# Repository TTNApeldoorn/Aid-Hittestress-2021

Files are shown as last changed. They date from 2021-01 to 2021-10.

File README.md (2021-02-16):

# Aid-Hittestress-2021

## About this repository
This repository holds all information te build de AiD-Heatstress-sensor. 

**At this moment the repository presents work in progress. Changes may accur any time without notice!!**

# Disclaimer
The documentation of the TTN-Apeldoorn Aid-Hittestress-2021 sensor is distributed in the hope that it will be useful, but WITHOUT ANY WARRANTY; without even the 
implied warranty of MERCHANTABILITY or FITNESS FOR A PARTICULAR PURPOSE.

# License
The TTN-Apeldoorn Aid-Hittestress-2021 sensor is free soft- and hardware:
you can redistribute and/or modify it under the terms of a Creative Commons Attribution-NonCommercial 4.0 International License (http://creativecommons.org/licenses/by-nc/4.0/) by TTN-Apeldoorn (https://www.thethingsnetwork.org/community/apeldoorn/) E-mail: ttnapeldoorncoreteam@rfsee.nl

<br />This work is licensed under a <a rel="license" href="http://creativecommons.org/licenses/by-nc/4.0/">Creative Commons Attribution-NonCommercial 4.0 International License</a>.

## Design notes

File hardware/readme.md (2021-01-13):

# Hardware for Hittestress 2021 node.

## Documentation

## PCB design

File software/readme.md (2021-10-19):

# Software for Hittestress 2021 Node

The hittestress node is based on a Heltec SpaceCube board. This board offers besides a good LoRa stack, deep sleep facilities, LiPo power management, enough program memory and sufficient IO possibilities, see https://heltec.org/project/htcc-ab01/

### System Overview
Three sensors are connected to the node:

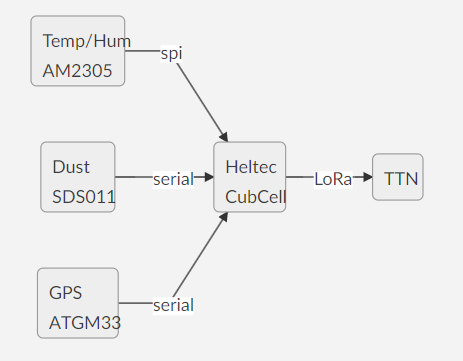
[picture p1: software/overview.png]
link


The Sensor sends each two minutes the Temperature, Humidity, Dust, PM10/PM2,5 to TTN. Each 4 hours the Status and GPS position of the sensor is send to TTN.

### Prototype
The development is currently in a prototyping phase. 
Below the prototype wiring diagram. 
link

### Power management
AT night the sensor is powered by 220V, during daylight the sensor is powered by the 3.7V LiPo. At night the LiPo will be charged.
To save power consumption, the CubeCell is forced into a deep sleep between two message cycles.  The GPS is powered via pin Vext, which is only active when requesting the GPS location.  The dust sensor SDS011 is forced in a sleep by a software command. The SDS011 air-fan needs 5V, so a DC step-up is placed in the supply line.

### Software prerequisites
- Arduino development environmnet minumum version 1.8
- Cube-Cell Development Framework V1.3 (can be installed in the Arduino board manager)
- DHT Adafruit sensor library
- TinyGPS++ library (Mikal Hart)

The LoRa stack and the SoftwareSerial is part of the CubeCell core. The adapted SDS011 library is present in the Hittestress source code.

### Arduino settings
Be sure that the correct board is selected and select the correct LoraWan parameters in the menu Arduino->tools:
- Board: CubeCel-Board (HTTC-AB01)
- LORAWAN settings: 
  - REGION_EU868
  - CLASS_A
  - OTAA
  - ADR ON
  - Upload UNCONFIRMED
  - Net Reservation OFF,
  - AT Support OFF,
  - RGB DEACTIVE   !!
  - Debug None

Note: RGB must be deactivated otherwise a conflict occurs with the GPS powersuppply Vext.
  
### TTN keys
The following OTAA keys must be set in the file LoRaWan.h viz. **appEui** and **appKey**.
**devEui** key must be left empty, this one is automatically set from the unique chipid of the HellTec board during startup.
This makes it possible the use of the same code for multiple sensors in your project.

### Payload binary 
Messages are sent on TTN port 15 (measurement data) and port 16 (status data)

Measurement payload on port 15:
- byte 0, 1:  Int16; Temperature * 100
- byte 2, 3: Int16; Humidity * 100
- byte 4, 5: Int16; PM10 * 100
- byte 6, 7: Int16; PM2.5 * 100
- byte 8, 9: Int16; Vbatttery * 1000

Status Payload on port 16:
- byte 0-3: Float: Latitude
- byte 4-7: Float: Longitude
- byte 8, 9: Int16; Altitude
- byte 10,11: InT16; Hdop * 1000
- byte 12,13: Int16; Vbatttery * 1000
- byte 14,15: Int16; Software version * 100

Note: Status message is sent each hour

### Output Payload decoder
The Payload decoder converts the binary payload to Json.<br>
Json example of a measurement message:
```
{ 
  "pm10": 0.9,
  "pm2p5": 0.46,
  "rh": 56.3,
  "temp": 7.5,
  "vbat": 4.17
}
```
Json Example of a status message
```
{ 
  "latitude": 52.2184104,
  "longitude": 5.964393,
  "alt": 56,
  "hdop": 1.8,
  "vbat": 4.026,
  "SwVer": 0.9
}
```

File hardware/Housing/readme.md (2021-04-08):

# Acrylic holder for SDS011
This holder is designed to hold the SDS011 sensor inside the sensor housing.

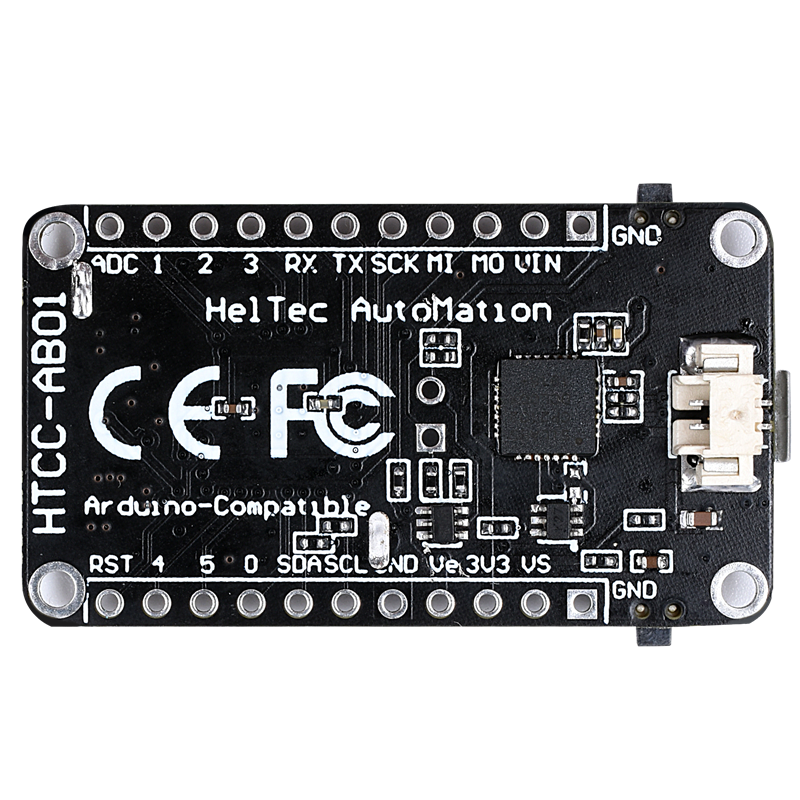
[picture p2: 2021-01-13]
hardware/documentation/board003.png

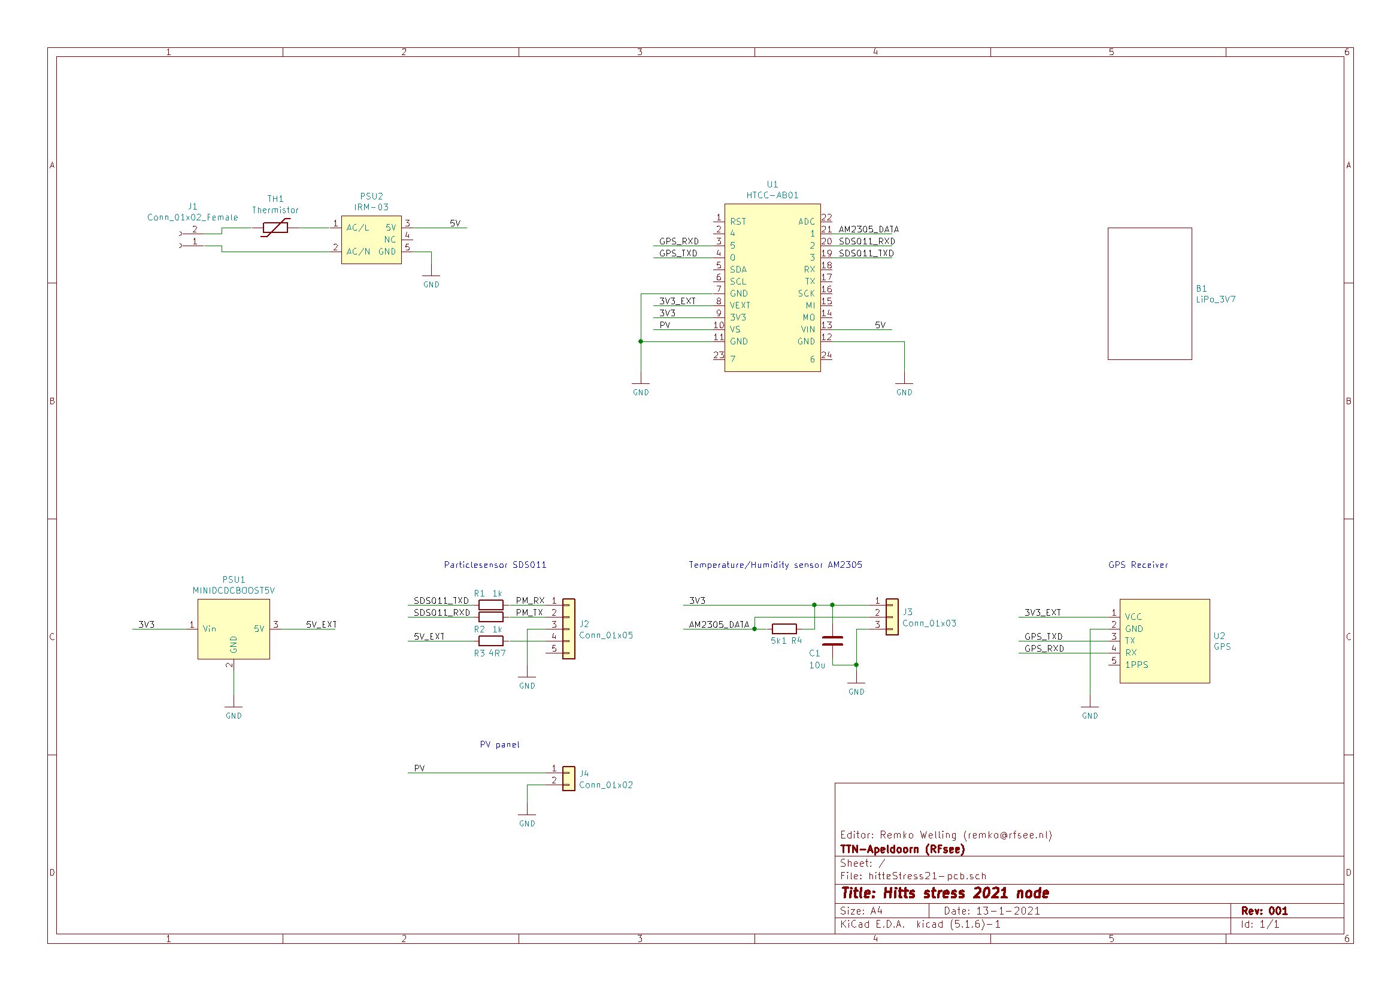
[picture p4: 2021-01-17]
hardware/pcb/hittstressV2_PCB_001.jpg

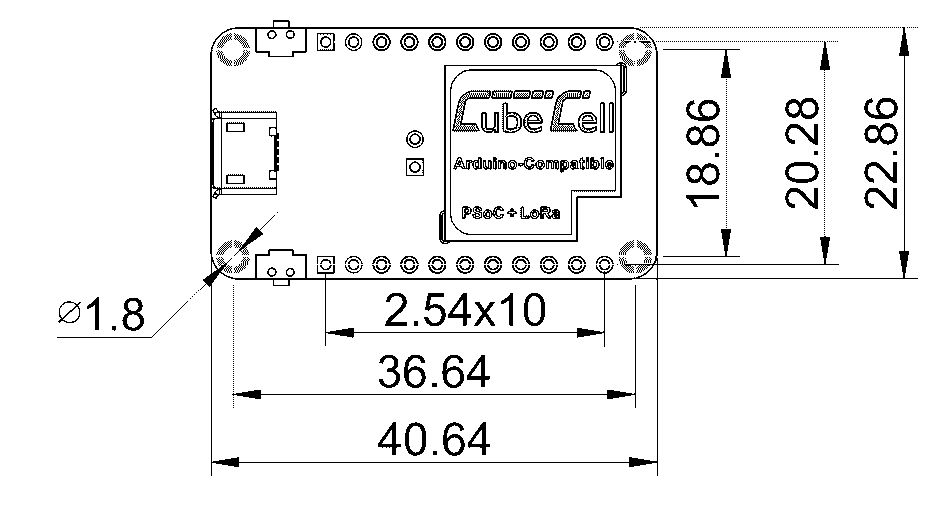
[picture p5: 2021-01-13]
hardware/documentation/BoardLayOut.jpg

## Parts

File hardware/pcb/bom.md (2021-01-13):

# BOM

## Mini DC-DC 5V Step-up Boost Converter 480mA
https://www.tinytronics.nl/shop/en/dc-dc-converters/step-up-(boost)/mini-dc-dc-5v-step-up-boost-converter-480ma

A small boost converter with output voltage of 5V.

Specifications:

    Input voltage range: 0.9 - 5V 
    Output voltage: 5V (fixed)
    Output current: 480 mA (max)
    Efficiency: ~85%
    Dimensions: 11 x 10.5 x 7.5 mm 

The  maximum output voltage is dependent on the input voltage:
|Input voltage(V)|Output current(mA)|
|--|--|
|0.9|7|
|1-1.5|40 - 100|
|1.5 -2 |100-150|
|2-3|150-380|
|>3|480|

The pinout (Vi, GND, Vo) is indicated on the module:

    Vi: Positive voltage input (paired with GND/min)
    GND: ground/min
    Vo: Positive voltage output (paired with GND/min)

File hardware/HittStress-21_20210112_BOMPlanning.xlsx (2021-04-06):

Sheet: RS (16+4)
 |  |  | Development |  | 2 |  | For development and prototyping (1)
 |  |  | Manufactured |  | 20 | + | Delivered
 |  |  | Devices |  | 22 |  | Total devices to be produced
Required | n | Value | Footprint | price/st/net | staffel | count | Price(Ex) | Price |  |  |  | Shop | Datasheet
TRUE | 1 | Lithium Ion Polymeer Accu - 3.7v 1200mAh |  | €9.58 | 1 | 22 | €210.76 | €255.02 | 22 |  |  | Kiwi Electronics | KW-2152
TRUE | 1 | Behuizing |  | €34.15 | 5 | 22 | €853.75 | €1033.04 | 25 |  |  | RS-Components | https://nl.rs-online.com/web/p/products/7560007/
TRUE | 1 | Voeding |  | €6.17 | 1 | 22 | €135.74 | €164.25 | 22 |  |  | RS-Components | https://nl.rs-online.com/web/p/products/1359226/
TRUE | 1 | AM2305 |  | €15.00 | 1 | 22 | €330.00 | €399.30 | 22 |  |  | Ali express ? | Stelpost
TRUE | 1 | Dubbelzijdige PCB 3x |  | €11.71 | 1 | 22 | €257.62 | €311.72 | 22 |  |  | Aisler
TRUE | 1 | SDS011 |  | €20.00 | 1 | 22 | €440.00 | €532.40 | 22 |  |  | Ali express ? | Stelpost
TRUE | 1 | SDS011 behuizingen |  | €2.00 | 1 | 22 | €44.00 | €53.24 | 22 |  |  | HOZA | Stelpost
TRUE | 3 | Wartels |  | €4.80 | 5 | 66 | €336.00 | €406.56 | 70 |  |  | HOZA | Stelpost
TRUE | 1 | LittleIfuse 0,05A |  | €3.68 | 1 | 22 | €80.96 | €97.96 | 22 |  |  | RS-Components | https://nl.rs-online.com/web/p/products/7756034/
TRUE | 1 | RS PRO 5mm Pitch, 2 Way PCB Terminal Block |  | €0.42 | 10 | 22 | €12.72 | €15.39 | 30 |  |  | RS-Components | https://nl.rs-online.com/web/p/pcb-terminal-blocks/8971159
TRUE | 1 | RS PRO, 2 Way, 1 Row, Straight PCB Terminal Block Header |  | €0.24 | 10 | 22 | €7.32 | €8.86 | 30 |  |  | RS-Components | https://nl.rs-online.com/web/p/pcb-headers/8971367
TRUE | 1 | 2.54mm Pitch 3 Way 1 Row Straight PCB Socket |  | €0.48 | 10 | 22 | €14.40 | €17.42 | 30 |  |  | RS-Components | https://nl.rs-online.com/web/p/pcb-sockets/2518187/
TRUE | 1 | 2.54mm Pitch 5 Way 1 Row Straight PCB Socket |  | €0.72 | 10 | 22 | €21.69 | €26.24 | 30 |  |  | RS-Components | https://nl.rs-online.com/web/p/pcb-sockets/2518200/
TRUE | 2 | SSW 2.54mm Pitch 11 Way 1 Row Straight PCB Socket |  | €1.15 | 1 | 44 | €41.82 | €50.60 | 44 |  |  | RS-Components | https://nl.rs-online.com/web/p/pcb-sockets/1981643/
 | 0 |  |  | €1.36 | 3 | 0 | €0.00 | €0.00 | 0 |  |  | RS-Components
 | 0 |  |  | €6.67 | 1 | 0 | €0.00 | €0.00 | 0 |  |  | RS-Components
 | 0 |  |  | €2.03 | 5 | 0 | €0.00 | €0.00 | 0 |  |  | RS-Components
TRUE | 1 | SDS connector PCB |  | €2.03 | 5 | 22 | €50.75 | €61.41 | 25 |  |  | RS-Components | https://nl.rs-online.com/web/p/products/8201598/
TRUE | 1 | ATGM336H GPS |  | €5.00 | 1 | 22 | €110.00 | €133.10 | 22 |  |  | Ali express ?
TRUE | 2 | 1K |  | €0.12 | 10 | 44 | €6.00 | €7.26 | 50 |  |  | RS-Components | https://nl.rs-online.com/web/p/products/7078221/
TRUE | 1 | HTCC-AB01 |  | €11.99 | 1 | 22 | €263.78 | €319.17 | 22 |  |  | Helltec | Stelpost
TRUE | 1 | 4R7 |  | €0.10 | 25 | 22 | €2.50 | €3.02 | 25 |  |  | RS-Components | https://nl.rs-online.com/web/p/through-hole-fixed-resistors/6833806/
TRUE | 1 | 5K1 |  | €0.10 | 25 | 22 | €2.50 | €3.02 | 25 |  |  | RS-Components | https://nl.rs-online.com/web/p/through-hole-fixed-resistors/0148253/
 | 0 |  |  | €2.03 | 5 | 0 | €0.00 | €0.00 | 0 |  |  | RS-Components
 | 0 |  |  | €2.03 | 5 | 0 | €0.00 | €0.00 | 0 |  |  | RS-Components
 | 0 |  |  | €2.03 | 5 | 0 | €0.00 | €0.00 | 0 |  |  | RS-Components | Stelpost
TRUE | 1 | Wurth Elektronik, 2109 2.54mm Pitch, 3 Way PCB Terminal Block |  | €1.20 | 5 | 22 | €29.95 | €36.24 | 25 |  |  | RS-Components | https://nl.rs-online.com/web/p/pcb-terminal-blocks/1919097/
TRUE | 1 | Mini DC-DC 5V Step-up Boost Converter 480mA |  | €1.65 | 1 | 22 | €36.30 | €43.92 | 22 |  |  | Tinytronics | https://www.tinytronics.nl/shop/en/dc-dc-converters/step-up-(boost)/mini-dc-dc-5v-step-up-boost-converter-480ma
 |  |  |  |  |  |  | Ex | VAT |  |  | +
 |  |  | Subtotaal |  |  |  | €3288.56 | €3979.16 |  | €0.00
 |  |  | Onvoorzien | 10% |  |  | €328.86
 |  |  |  |  |  |  |  |  |  |  | +
 |  |  |  |  |  |  | €3617.41 | €4377.07 |  | €4377.07 |  | Project price excl.VAT for 20 devices
 |  |  |  |  |  |  | €180.87 | €218.85 |  |  |  | Commercial Price/Pice excl.VAT
 |  |  |  |  |  |  |  | €198.96 |  |  |  | Community Price/Pice incl.VAT

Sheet: BOM
Ref | n | Value | Footprint | Shop | Datasheet
C1 | 1 | 10n | SMD:1206_3216 | RS-Components | https://nl.rs-online.com/web/p/mlccs-multilayer-ceramic-capacitors/2989220/
D1 | 1 | BAT54S | SMD:SOT-23 | RS-Components | https://nl.rs-online.com/web/p/rectifier-diodes-schottky-diodes/5444584/
J1 | 1 | RJ11-6 | RJ12_Amphenol_54601 | RS-Components | https://nl.rs-online.com/web/p/ethernet-connectors/1370999/
Q1 | 1 | BC547 (BC847) | SMD:SOT-323_SC-70 (SOT23) | RS-Components | https://nl.rs-online.com/web/p/bjt-bipolar-transistors/6900091/
R1, | 1 | 10K | SMD:R_1206_3216 | RS-Components | https://nl.rs-online.com/web/p/surface-mount-fixed-resistors/7219908/
R2, R3, R4, R8 | 1 | 1K | SMD:R_1206_3216 | RS-Components | https://nl.rs-online.com/web/p/surface-mount-fixed-resistors/9013724/
R5, R6, R7 | 3 | 180 | SMD:R_1206_3216 | RS-Components | https://nl.rs-online.com/web/p/surface-mount-fixed-resistors/7219762/
Housing | 1 |  | Hammond 1591 ABS Enclosure, Flanged | RS-Components | https://nl.rs-online.com/web/p/general-purpose-enclosures/8180514/
PCB | 1 |  | Aisler, PCB & Stencil | Aisler | http://www.aisler.net
header | 2 | FemalePCBHeader | 1 Row Straight PCB Socket | RS-Components | https://nl.rs-online.com/web/p/pcb-sockets/0252399/
U1 | 1 | TTGO_LoRa32_V11 | TTGO LoRa32 | Tinytronics | https://www.tinytronics.nl/shop/nl/platforms/ttgo/lilygo-ttgo-lora32-868mhz-esp32
Cable | 1 | RJ11 | InLine Modularkabel RJ12, Male/Male, 6adrig, 6P6C, 1m | Netwerkwinkel.com | https://www.netwerkwinkel.com/Verleng--en-aansluitkabels/Telefoonkabels/RJ10---RJ11---RJ12-kabels/InLine/InLine-Modularkabel-RJ12-Male-Male-6adrig-6P6C-2m-188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
PSU | 1 | 5V-miniUSB-Adapter | 5W Plug In Power Supply 5V dc, 1A | RS-Components | https://nl.rs-online.com/web/p/ac-dc-adapters/1217116/
miniUSB | 1 | Type B Mini USB Connector | Through Hole Mount Receptacle | RS-Components | https://nl.rs-online.com/web/p/usb-connectors/6741350/
J | 1 |  |  | RS-Components | https://docs.rs-online.com/898e/0900766b8157d634.pdf

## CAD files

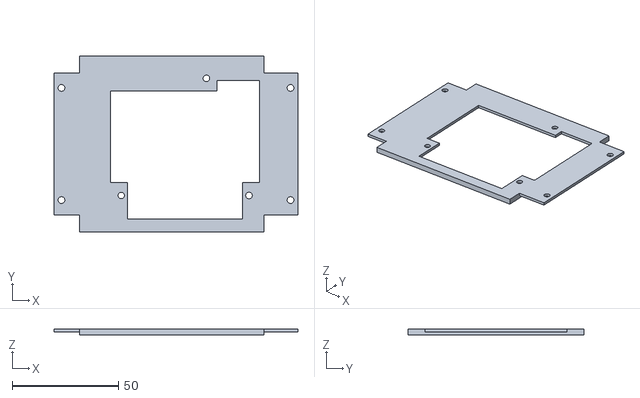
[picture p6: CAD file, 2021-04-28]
hardware/Housing/SDS011Mount-3D_004.stl
114.6 x 82.6 x 2.90

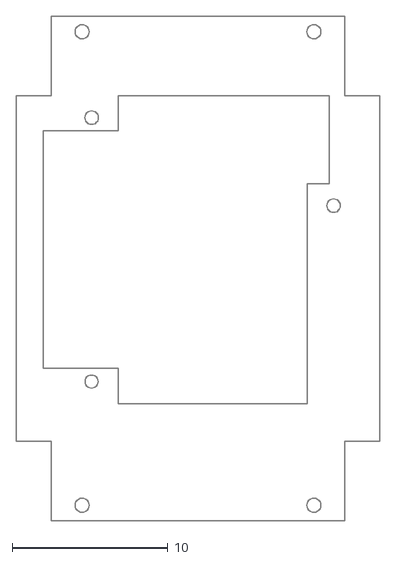
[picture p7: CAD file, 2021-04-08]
hardware/Housing/SDS011Mount_004.dxf
23.3 x 32.3

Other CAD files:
hardware/documentation/CubeCell_CAD2014.dwg
hardware/Housing/HousingDrillMeasures_001.skp
hardware/Housing/SDS011Mount-3D_004.skp
hardware/Housing/SDS011Mount_001.skp
hardware/Housing/SDS011Mount_002.skp
hardware/Housing/SDS011Mount_003.skp
hardware/Housing/SDS011Mount_004.skp

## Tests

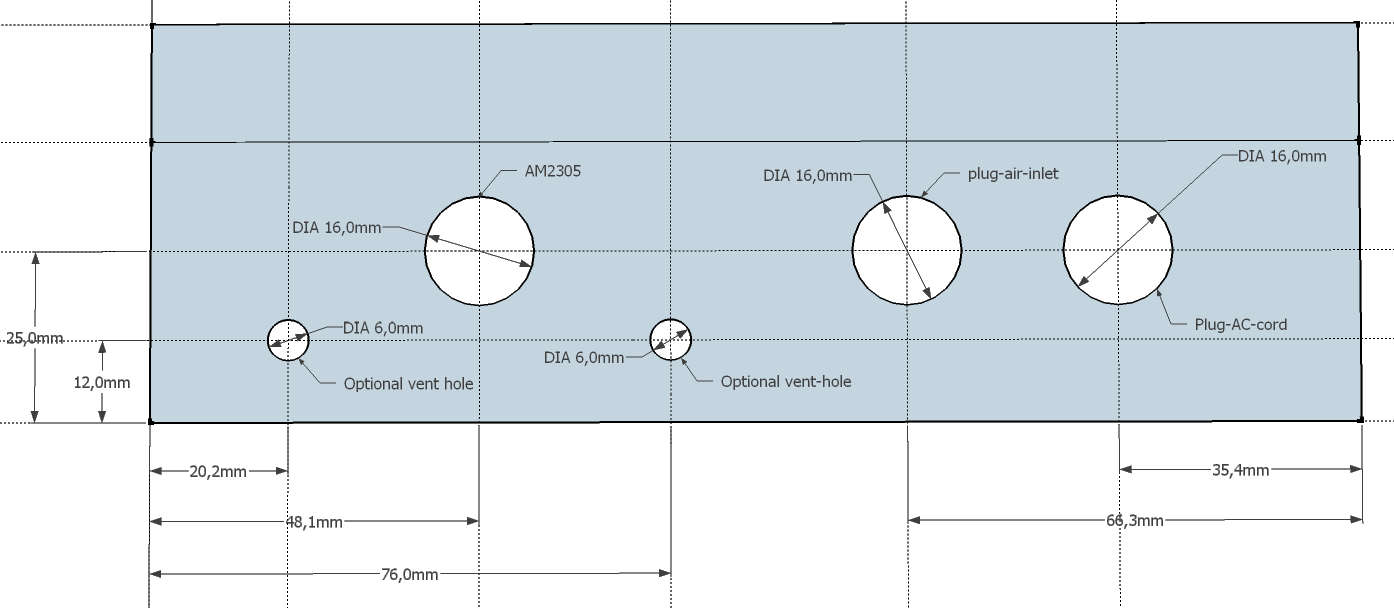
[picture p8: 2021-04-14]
hardware/Housing/HousingDrillMeasures_001_transparent.png

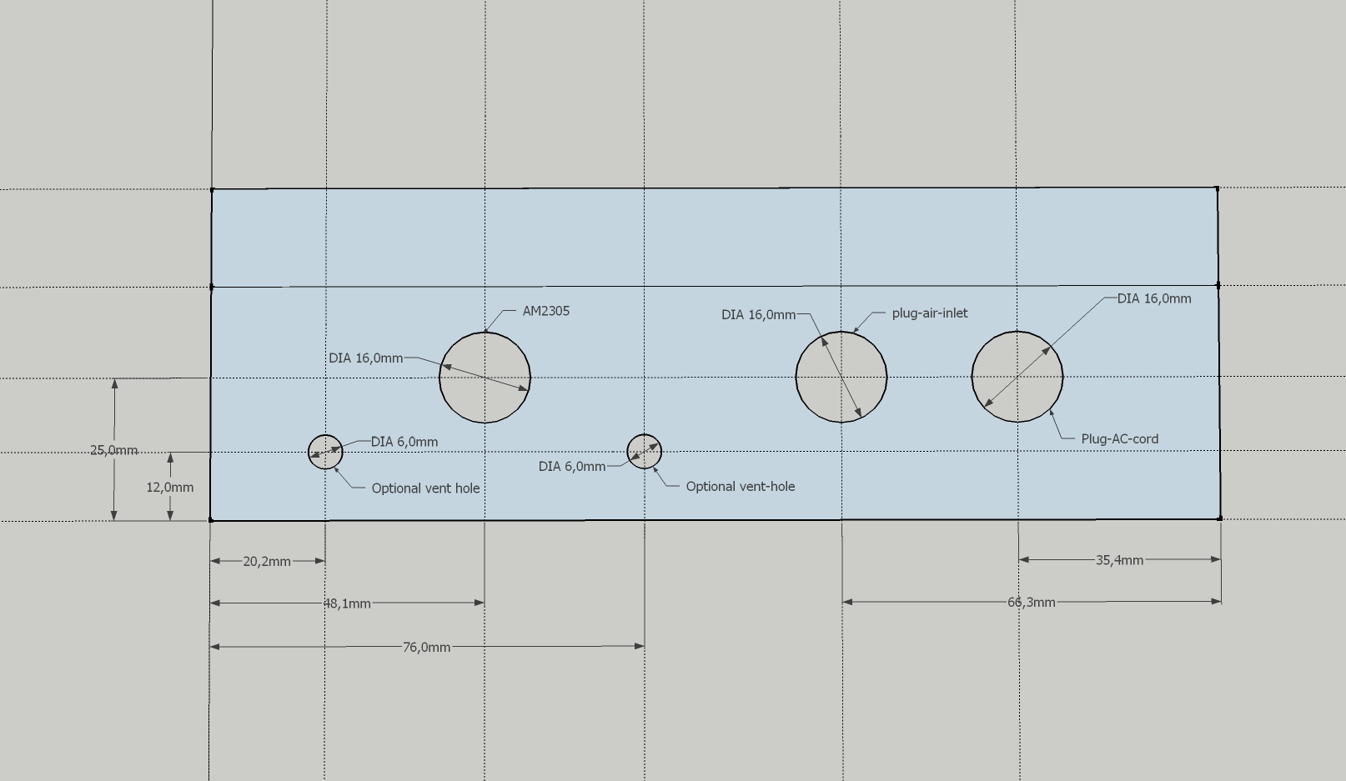
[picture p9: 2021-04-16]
hardware/Housing/HousingDrillMeasures_001.png

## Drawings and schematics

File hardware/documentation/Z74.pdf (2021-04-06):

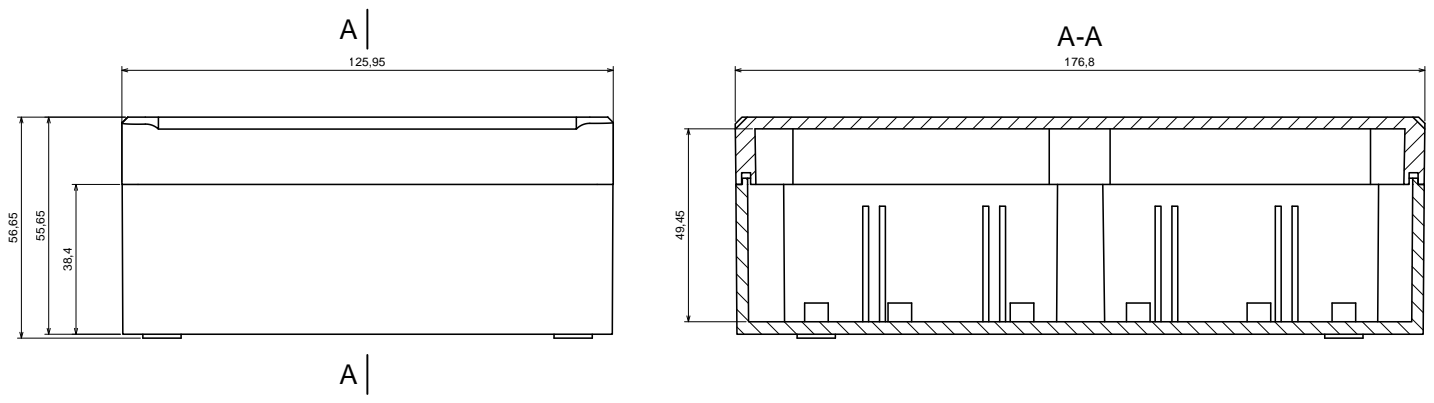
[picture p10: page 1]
Product model Format: A3 Scale 1:1; Tolerance: +/- 0.5 Material: PS, ABS Enclosure Z74 - assembly All rights reserved, Copyright Kradex 2016

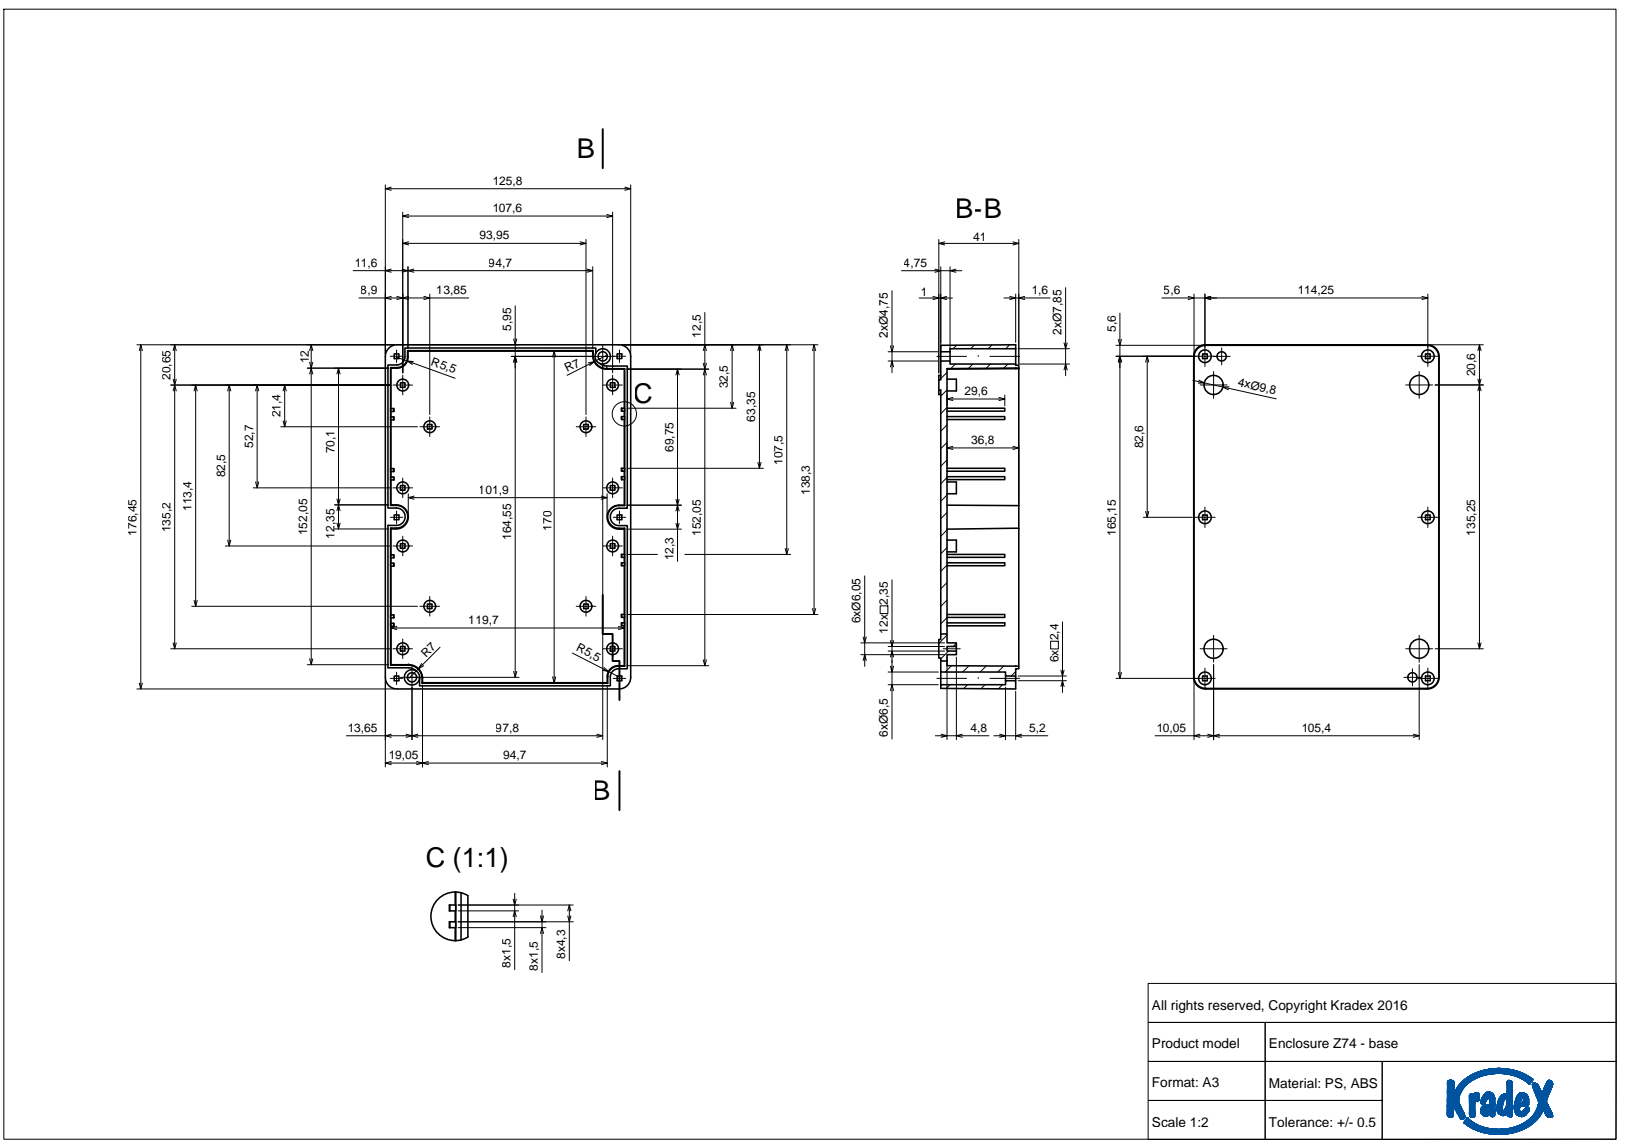
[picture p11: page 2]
Product model Format: A3 Scale 1:2; Tolerance: +/- 0.5 Material: PS, ABS Enclosure Z74 - base All rights reserved, Copyright Kradex 2016 125,8

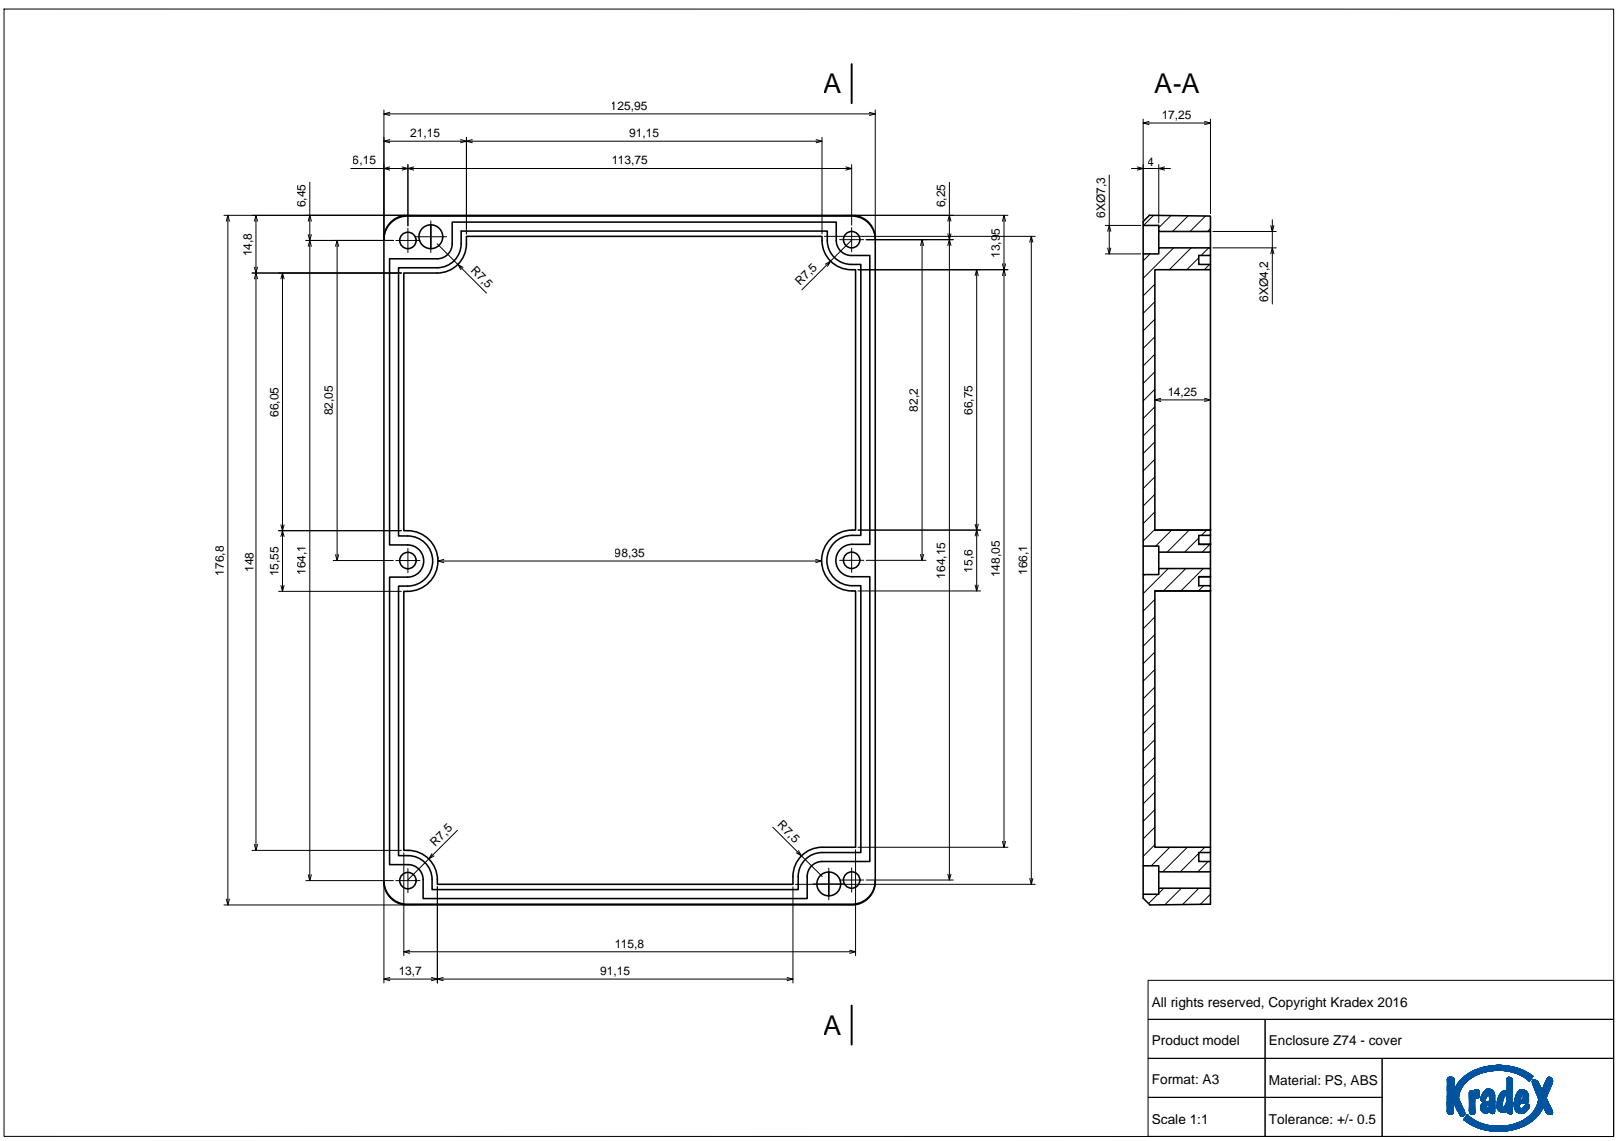
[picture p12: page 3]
Product model Format: A3 Scale 1:1; Tolerance: +/- 0.5 Material: PS, ABS Enclosure Z74 - cover All rights reserved, Copyright Kradex 2016 AA

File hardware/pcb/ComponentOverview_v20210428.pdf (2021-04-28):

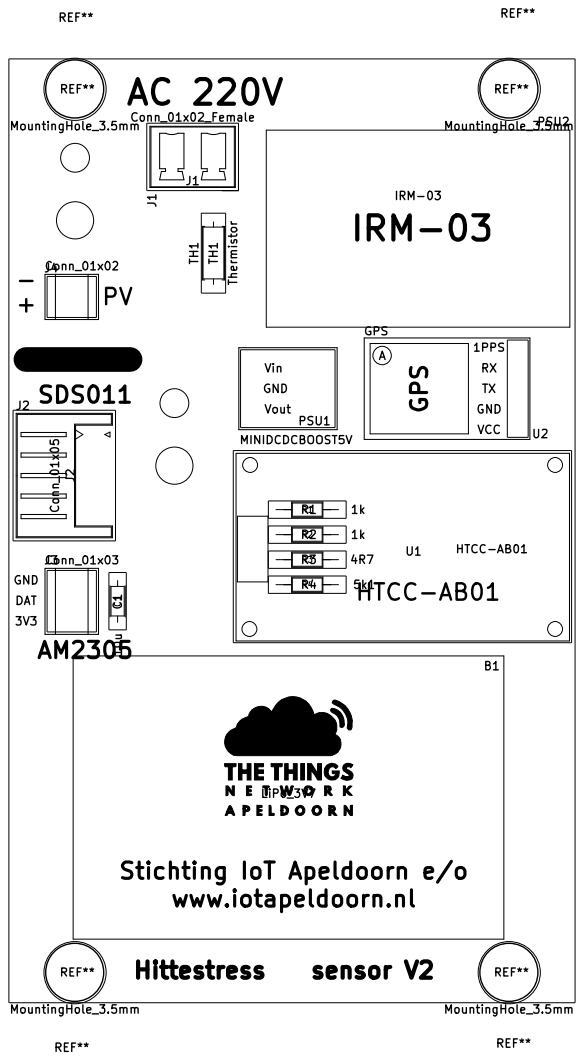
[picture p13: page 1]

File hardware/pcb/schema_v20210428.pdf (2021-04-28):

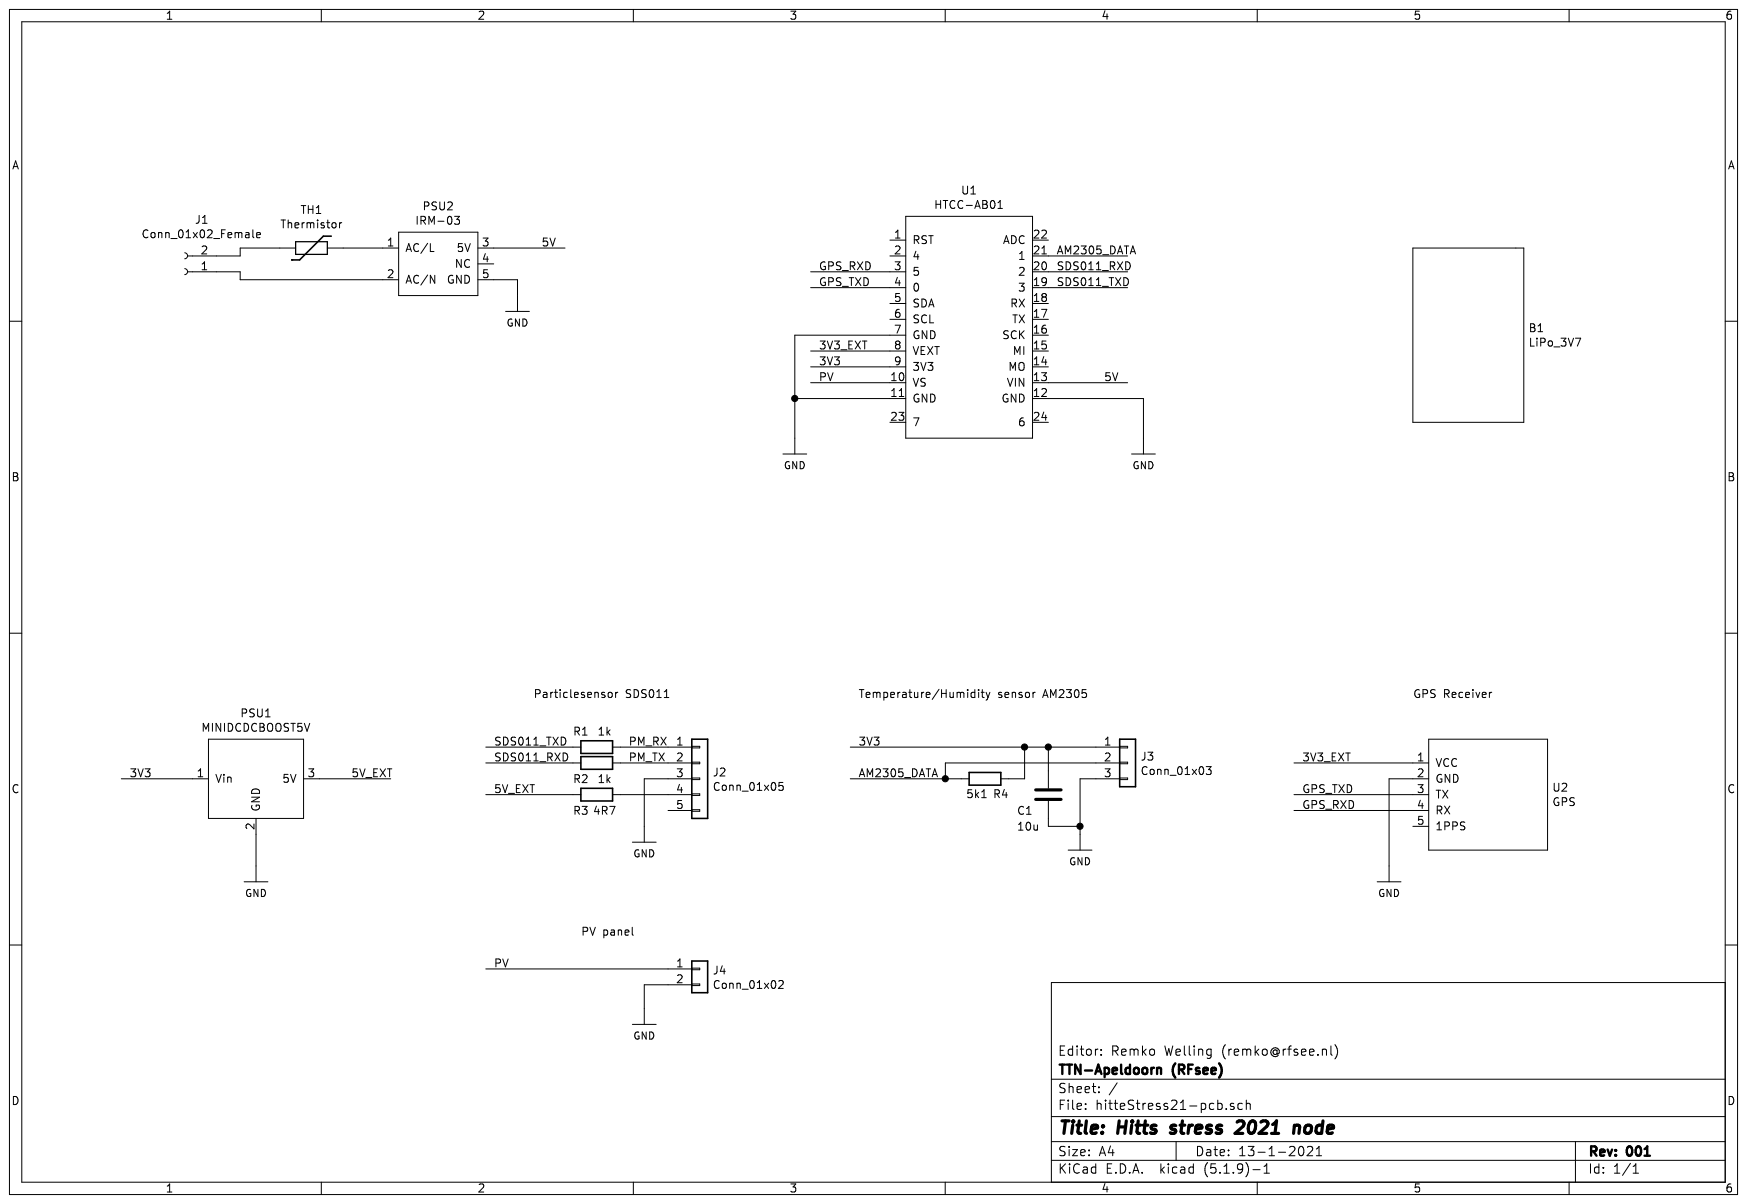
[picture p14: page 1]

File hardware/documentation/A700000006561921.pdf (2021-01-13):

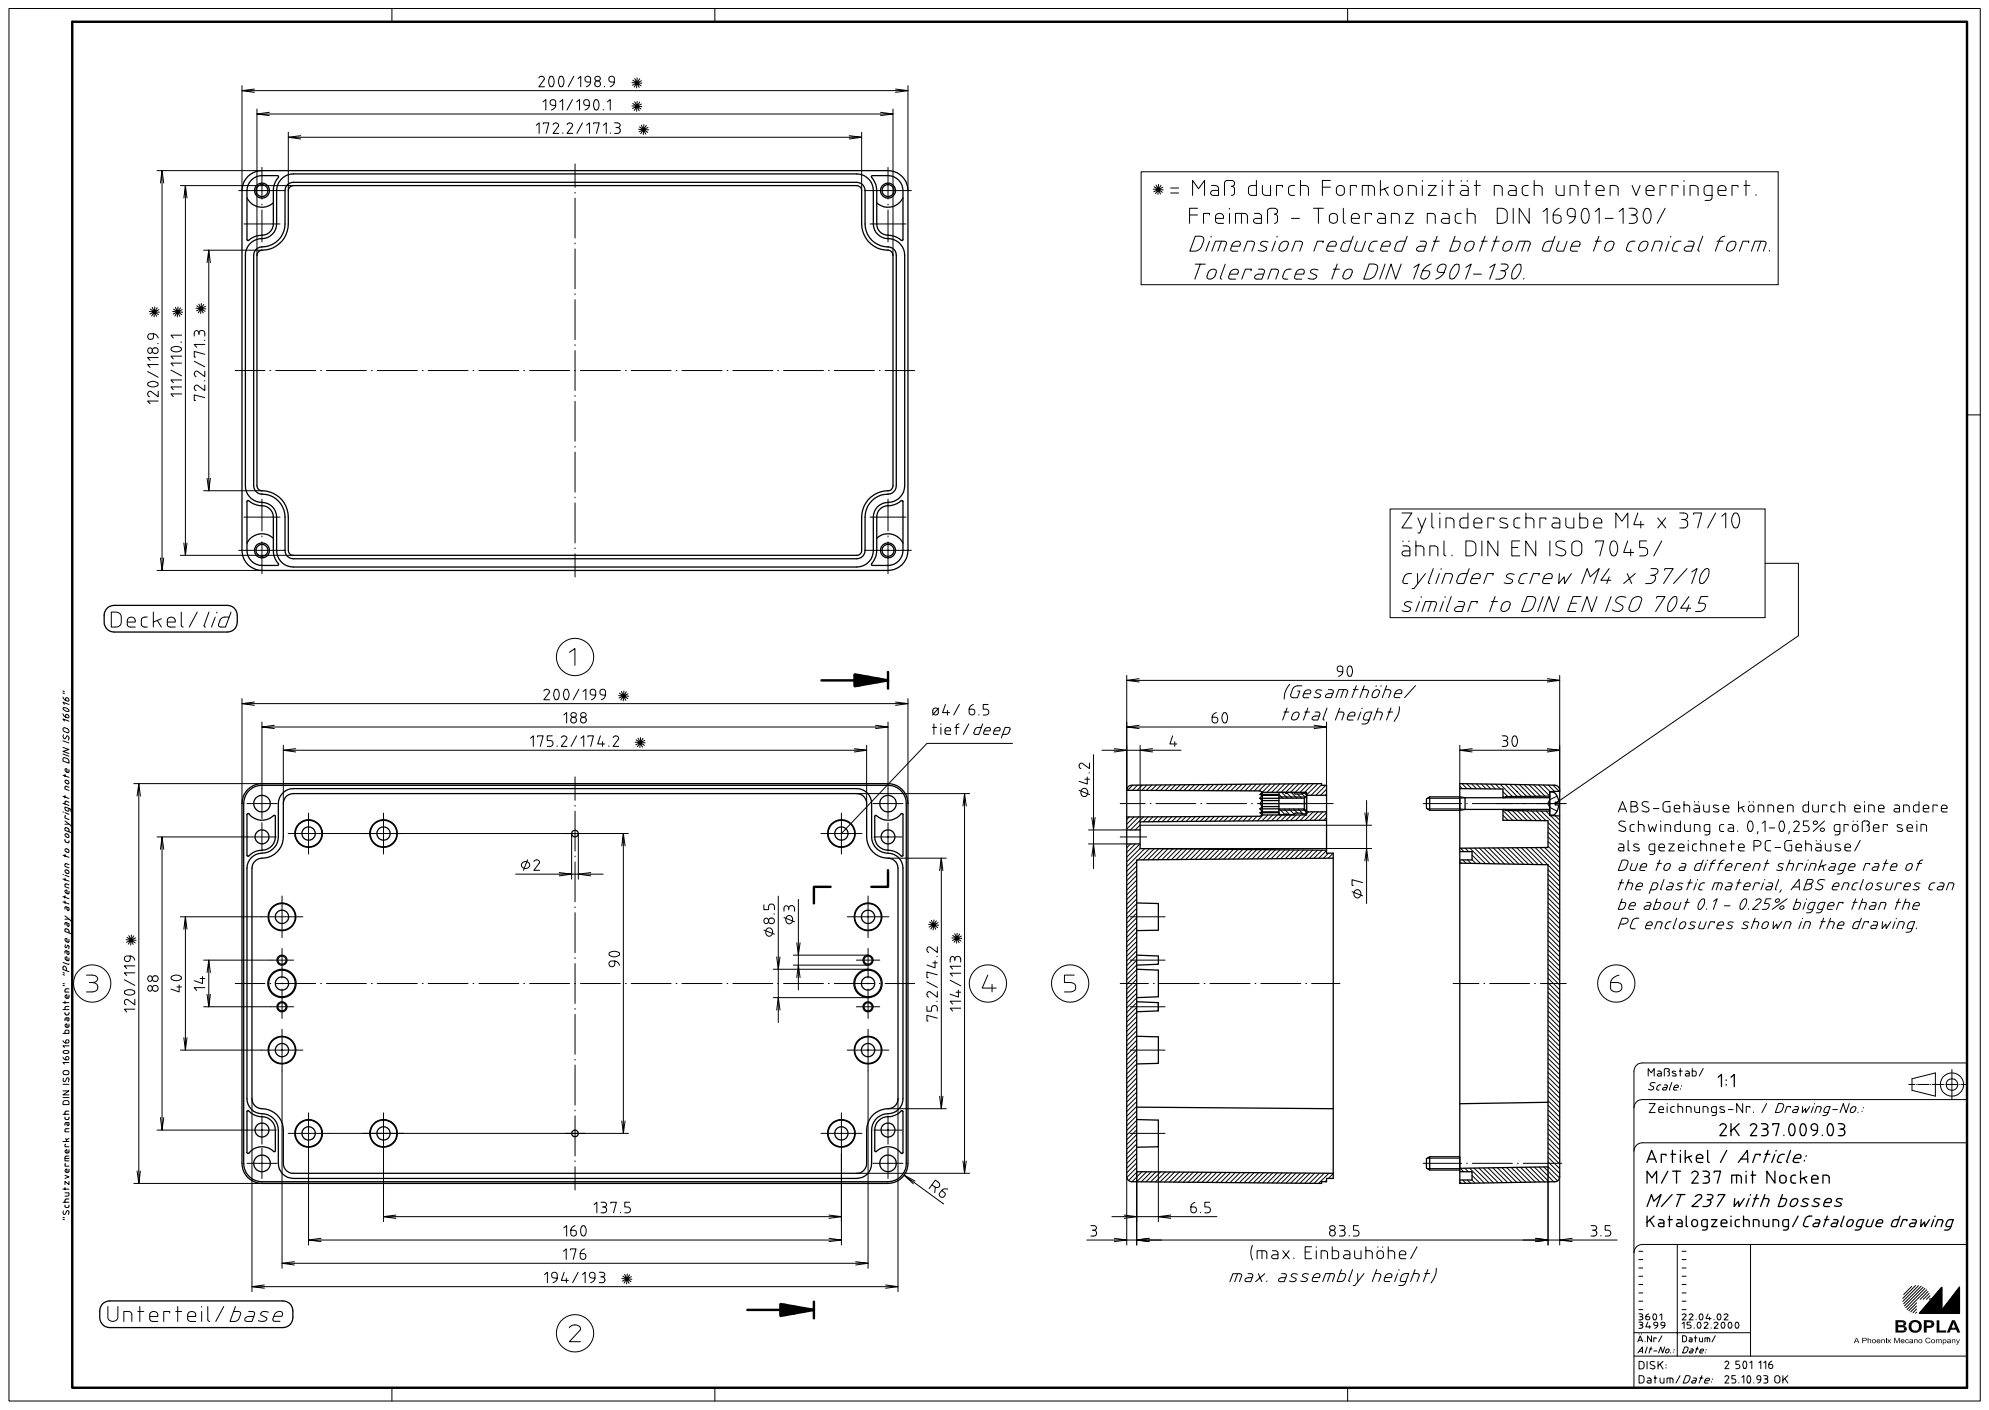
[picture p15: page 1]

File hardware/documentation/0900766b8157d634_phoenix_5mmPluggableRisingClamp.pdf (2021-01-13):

# Datasheet

# ENGLISH

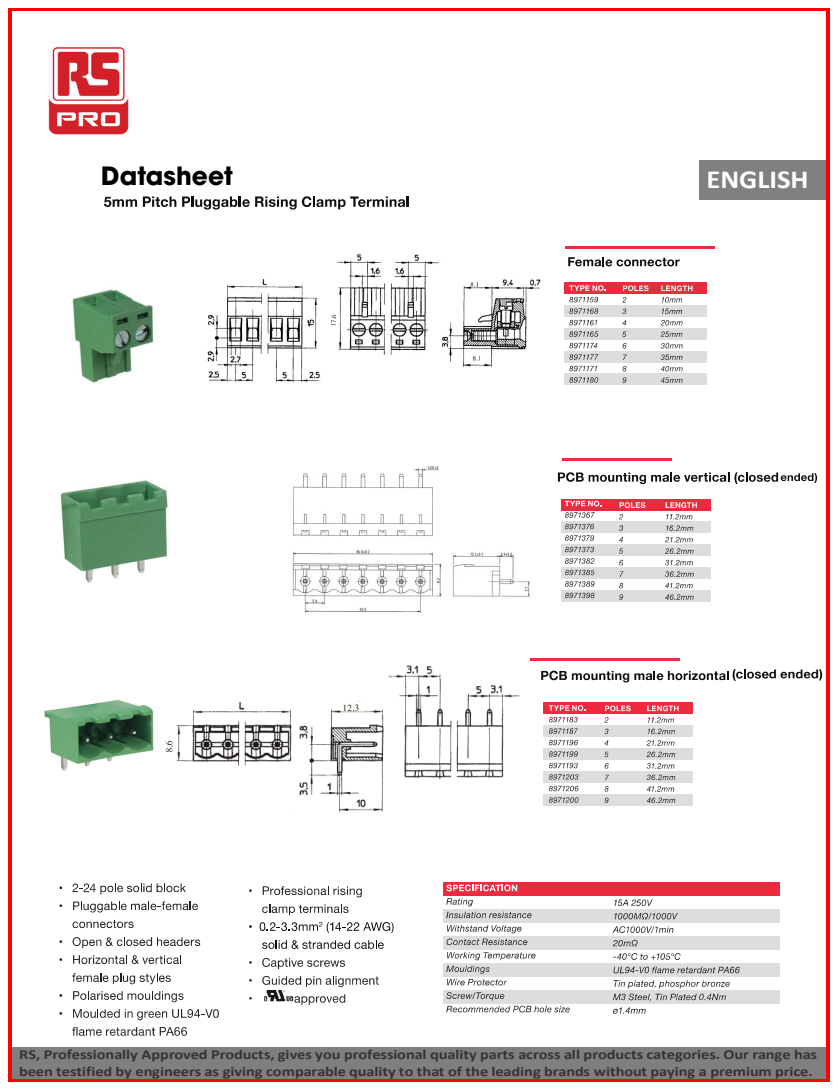
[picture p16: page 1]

RS, Professionally Approved Products, gives you professional quality parts across all products categories. Our range has
been testified by engineers as giving comparable quality to that of the leading brands without paying a premium price.

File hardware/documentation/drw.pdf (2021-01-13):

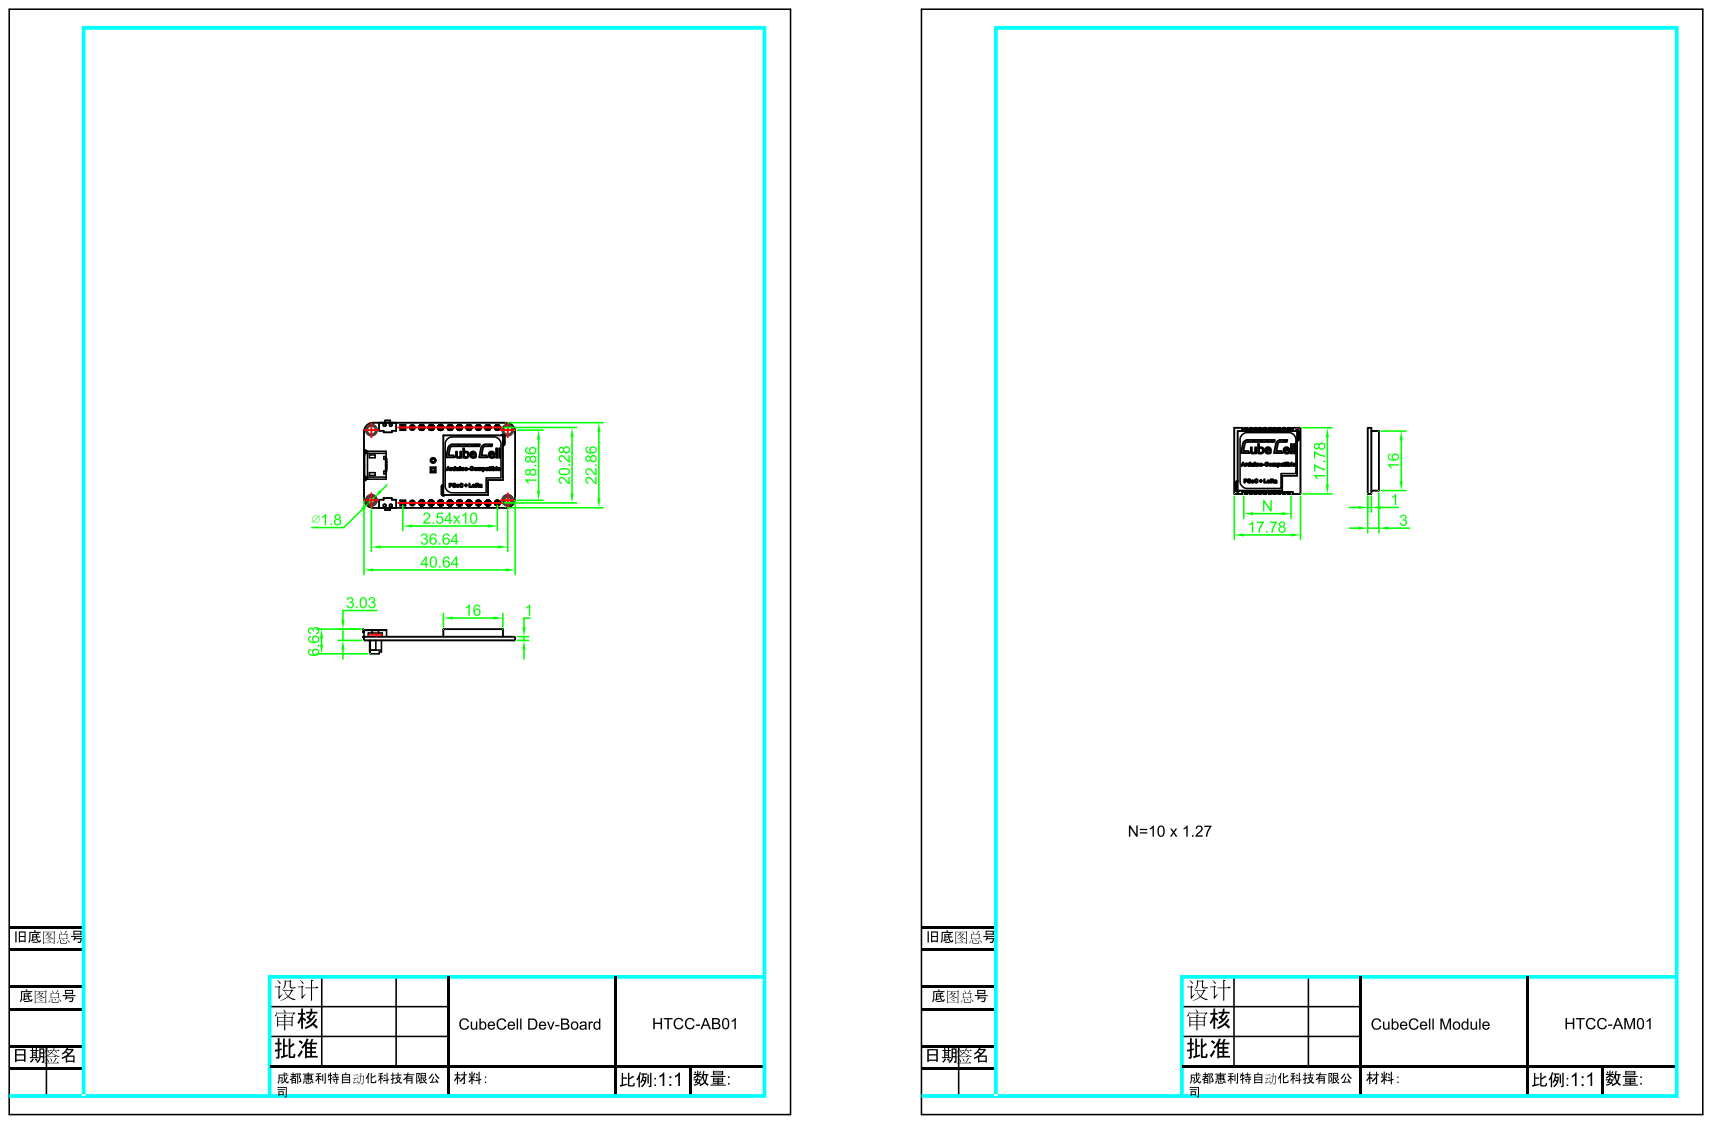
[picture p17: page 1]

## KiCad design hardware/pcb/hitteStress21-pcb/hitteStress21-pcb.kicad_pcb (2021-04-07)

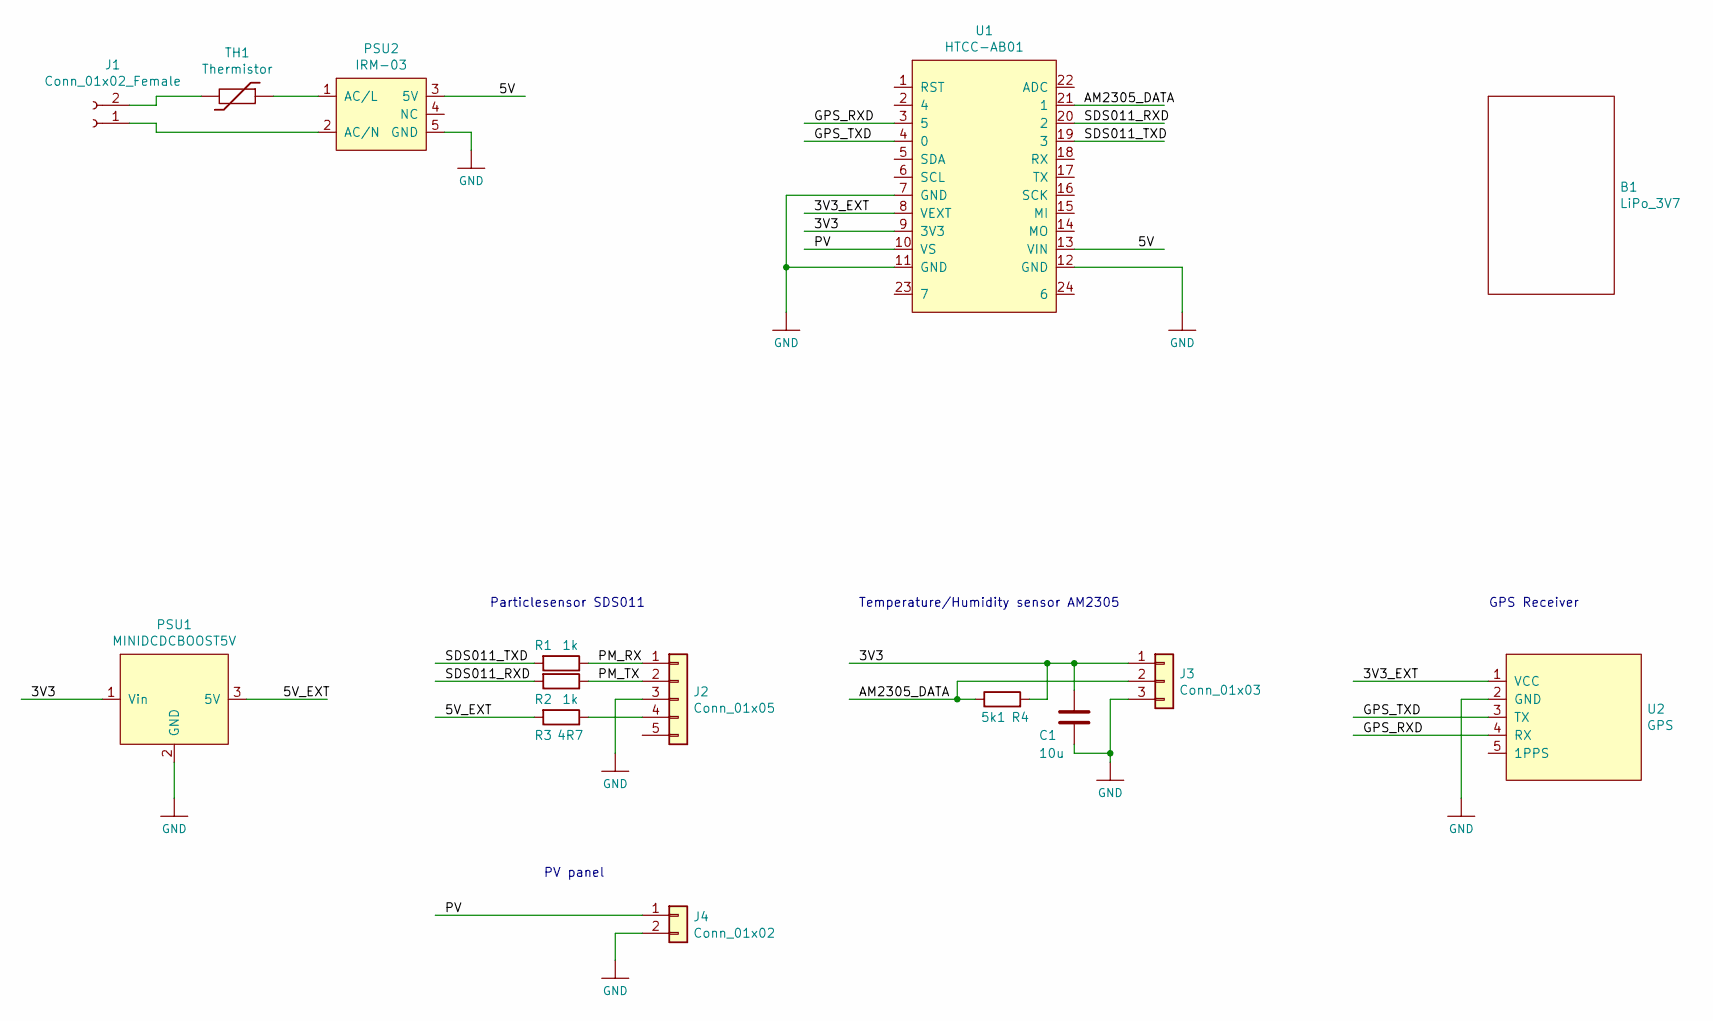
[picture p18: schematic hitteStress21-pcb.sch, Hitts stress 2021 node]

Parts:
B1: LiPo_3V7; LiPo_3V7_2000mAh_JST-PH
C1: 10u; R_Axial_DIN0204_L3.6mm_D1.6mm_P5.08mm_Horizontal
J1: Conn_01x02_Female; PhoenixContact_MCV_1,5_2-G-5.08_1x02_P5.08mm_Vertical
J2: Conn_01x05; JST_XH_S5B-XH-A_1x05_P2.50mm_Horizontal
J3: Conn_01x03; Wurth_2109_p2.54
J4: Conn_01x02; Wurth_2109_P2.54_2x1
PSU1: MINIDCDCBOOST5V; MINIDCBOOST5V
PSU2: IRM-03
R1, R2: 1k; R_Axial_DIN0204_L3.6mm_D1.6mm_P7.62mm_Horizontal
R3: 4R7; R_Axial_DIN0204_L3.6mm_D1.6mm_P7.62mm_Horizontal
R4: 5k1; R_Axial_DIN0204_L3.6mm_D1.6mm_P7.62mm_Horizontal
TH1: Thermistor; R_Axial_DIN0207_L6.3mm_D2.5mm_P7.62mm_Horizontal
U1: HTCC-AB01
U2: GPS

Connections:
/3V3: C1.1, J3.1, PSU1.1 (Vin), R4.2, U1.9 (3V3)
/3V3_EXT: U1.8 (VEXT), U2.1 (VCC)
/5V: PSU2.3 (5V), U1.13 (VIN)
/5V_EXT: PSU1.3 (5V), R3.2
/AM2305_DATA: J3.2, R4.1, U1.21 (1)
/GPS_RXD: U1.3 (5), U2.4 (RX)
/GPS_TXD: U1.4 (0), U2.3 (TX)
/PM_RX: J2.1, R1.1
/PM_TX: J2.2, R2.1
/PV: J4.1, U1.10 (VS)
/SDS011_RXD: R2.2, U1.20 (2)
/SDS011_TXD: R1.2, U1.19 (3)
GND: C1.2, J2.3, J3.3, J4.2, PSU1.2 (GND), PSU2.5 (GND), U1.7 (GND), U1.11 (GND), U1.12 (GND), U2.2 (GND)
unnamed: J1.1, PSU2.2 (AC/N)
unnamed: J1.2, TH1.2
unnamed: J2.4, R3.1
unnamed: PSU2.1 (AC/L), TH1.1

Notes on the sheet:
Particlesensor SDS011
Temperature/Humidity sensor AM2305
GPS Receiver
PV panel

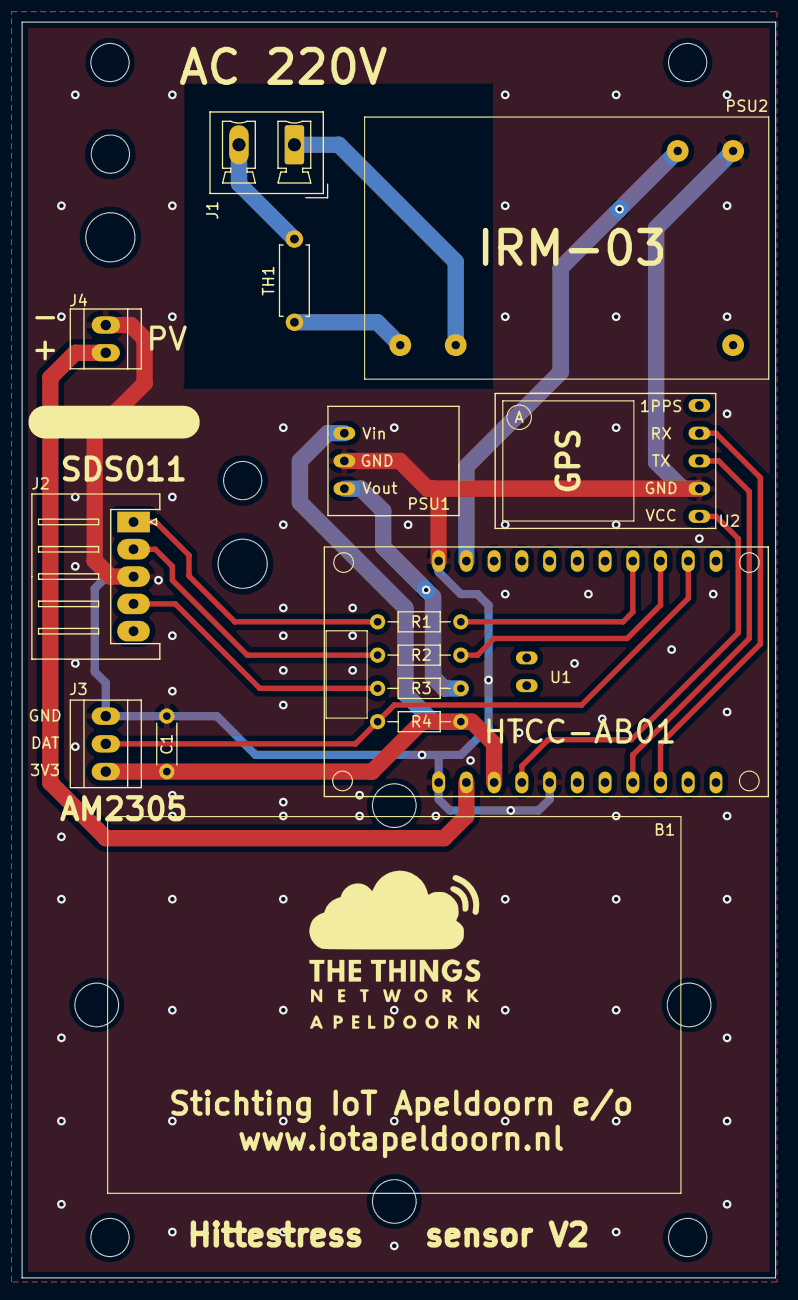
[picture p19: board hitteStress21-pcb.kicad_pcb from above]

Board: 2 copper layers, 69.0 x 115.0 mm, 15 parts (0 on the bottom side), 17 nets.

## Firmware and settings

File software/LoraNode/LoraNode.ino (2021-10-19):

/*--------------------------------------------------------------------
  Hittestress 2021 LoRaNode based on Heltec CubeCell LoRa board
  Sensor is equipped with Temp/Hum AM2305, Dust sensor SDS011 and GPS ATGM33
  Libraries used: Heltec LoRaWan_APP, DHT, SDS011(refactored), SoftwareSerial, TinyGPS++

  Author Marcel Meek
  Date 13/1/2021
  Update 25/4/2021  measurement and status message separated resp. port 15 and 16
  --------------------------------------------------------------------*/
#include <TinyGPS++.h>
#include <softSerial.h>
#include "LoRaClass.h"

#include <DHT.h>
#include "SDS011.h"

#define CYCLETIME  150000     // LoRa message cycle time  24 messages per hour
#define GPSTIMEOUT 120000    // max timeout to get a GPS fix
#define VERSION 1.5

// payload structs
struct Measurement {
  int16_t  temp, hum, pm2_5, pm10, batt;
};
struct Status {
  float lat, lng;
  int16_t alt, hdop, batt, version;
};

#define GPS_RX  GPIO0
#define GPS_TX  GPIO5
#define SDS_RX  GPIO3
#define SDS_TX  GPIO2

// NOTE: there are two SofwtareSerials, one for the SDS and one for the GPS. 
// They can't be used simultaneously. Instantiate them exclusively.
softSerial* portGPS = NULL;
softSerial* portSDS = NULL;
SDS011* sds = NULL;
LoRaClass lora;

static long msgCount = 0;           // message count
static int vbatCurr = INT_MAX, vbatPrev = INT_MAX;  // mV
static float prevPm10 = -1.0, prevPm25 = -1.0;
static bool resetRequest = false;

DHT dht(GPIO1, DHT22, 2);       // Initialize DHT (in our case AM2302) sensor for normal 16mhz Arduino

TinyGPSPlus tinyGpsPlus;  // The TinyGPS++ object


 // attach soft Serial to SDS and deattach GPS
void attachSDS() {
  if( portSDS == NULL) {
    delete portGPS;  portGPS = NULL;
    portSDS = new softSerial( SDS_TX, SDS_RX);
    portSDS->begin( 9600); delay( 100);
    sds = new SDS011( *portSDS);
  }
}

 // attach soft Serial to GPS and detach SDS
void attachGPS() {
  if( portGPS == NULL) {
    delete portSDS;  portSDS = NULL;
    delete sds; sds = NULL;
    portGPS = new softSerial( GPS_TX, GPS_RX);
    portGPS->begin( 9600); delay( 100);
  }
}

// check if battery is OK or battery is charging
bool isPowerOk() {
   vbatPrev = vbatCurr;
   vbatCurr = getBatteryVoltage();
printf("Vbat curr=%d\n", vbatCurr);
   return( vbatCurr > 3550 || vbatCurr-2 > vbatPrev); 
}


bool readDHT( float &t, float &h) {
   t = dht.readTemperature();
   h = dht.readHumidity();
   if( isnan(t)|| isnan(h)) {
     delay(1700);  Serial.println("AM2305 retry");  // minimum time to get new values from AM2305
     t = dht.readTemperature();
     h = dht.readHumidity();
   }
//Serial.print(t); Serial.print(" ");  Serial.println(h);
}

// read SDS dust sensor
// the sensor is read 5 times, the average value will be returnd
void readSDS( float &pm25, float &pm10) {
  // read 10 times and take average
  float sum25 = 0.0, sum10 = 0.0;
  int count = 0;

// 5 reads
  for(int i=0; i<5; i++) {
    delay( 1200);  
//Serial.print("."); // minimum time to get new values from SDS011
    if( sds->read( &pm25, &pm10) ) {
      sum10 += pm10;
      sum25 += pm25;   
//Serial.print(pm10); Serial.print(" "); 
      count++;
    }
  }
//Serial.println();
  // calculate average
  pm10 = sum10 / count;
  pm25 = sum25 / count;
  //printf("count=%d\n", count);

// take average with previous cycle
  if( prevPm10 > 0.0 ) {
    pm10 = (pm10+ prevPm10) / 2.0;
    pm25 = (pm25 + prevPm25) / 2.0;
  }
  prevPm10 = pm10;
  prevPm25 = pm25;
}

void processMeasurement( Measurement &m) {
  printf("processMeasurement\r\n");
  float t, h, pm25, pm10;
  readDHT( t, h);
  // start SDS fan to start airflow
  sds->wakeup();
  delay( 5000); // take 5 + 1.2 seconds for a good airflow
 
  //readDHT( t, h);  // take 5 seconds (also delay for airflow)
  // assume airflow is on speed
  readSDS( pm25, pm10);  
 
  m.temp = t * 100;
  m.hum = h * 100;
  m.pm2_5 = pm25 * 100;
  m.pm10 = pm10 * 100;
  m.batt = vbatCurr; 
  Serial.print( "temp="); Serial.print( t);
  Serial.print( " hum="); Serial.print(  h);
  Serial.print( " pm10="); Serial.print( pm10 );
  Serial.print( " pm25="); Serial.print( pm25);
  Serial.print( " batt="); Serial.println( vbatCurr);
  sds->sleep();
  delay(100);
}

// read Status
// return true, if a fix is detected within the timeout.
bool processStatus( Status &status) {
  printf("processStatus\n");
  bool fix = false;
  int i = 0;
  long start = millis();

  // leave loop after timout or
  // if Vext power is switched off, exit the loop (caused by RGB_LORAWAN Led, be sure that it is deactivated)
  while( millis() - start < GPSTIMEOUT && digitalRead(Vext) == 0) {   
    if( portGPS->available() > 0 ) {
      char c = portGPS->read();
      //Serial.print(c);
      tinyGpsPlus.encode( c); i++;
      if( tinyGpsPlus.location.isUpdated()) {
        status.lat = tinyGpsPlus.location.lat();
        status.lng = tinyGpsPlus.location.lng();
        status.hdop = 1000 * tinyGpsPlus.hdop.hdop();
        status.alt = tinyGpsPlus.altitude.meters();
        fix = true;
        break;
      }
    }
  }
  printf("GPS chars read:%d\n", i);
  status.batt = vbatCurr;
  status.version = VERSION * 100;
  Serial.print("lat: ");Serial.print( status.lat);
  Serial.print(" lon: ");Serial.print( status.lng);
  Serial.print(" alt: "); Serial.print( status.alt);
  Serial.print(" hdop: "); Serial.print( status.hdop / 1000.0);
  Serial.print(" batt: "); Serial.print( status.batt / 1000.0);
  Serial.print(" version: "); Serial.println( status.version / 100.0);

  return fix;
}

// prepare and send Lora Message
void procesSensors( ) {
  printf( "procesSensors\n");  

  if( msgCount % 96 == 1) {  // a status cycle (each 96 cycles, is each 4 hours)  
    digitalWrite(Vext, LOW);    // switch the gps power on
    attachGPS();
    Status status = {0.0, 0.0, 0, 0, 0, 0};
    processStatus( status);
    printf("send status len=%d\n", sizeof(status));
    attachSDS();
    digitalWrite(Vext, HIGH);   // switch gps power off 
    //loRaWan.sendMsg( 16, (void*)&status, sizeof(status));     // status lora port 16
    lora.send( 16, &status, sizeof(status));
  }
  else {  // send measurement
    Measurement measurement;
    processMeasurement( measurement);   // read temp, hum, and PM
    printf("send measurement len=%d\n", sizeof(measurement));
    //loRaWan.sendMsg( 15, (void*)&measurement, sizeof(measurement));  // data lora port 15
    lora.send( 15, &measurement, sizeof(measurement));
  }
}

// work process, called by the Heltec framework after deepsleep timeout
void worker( ) {
  printf("Worker %d\n", msgCount);
  long start = millis();

// check power
  if( isPowerOk() ) {
    procesSensors();
    msgCount++;
  }

  int sleeptime = CYCLETIME - (millis() - start);     // cycletime minus processtime
  if(sleeptime <20000)
     sleeptime = 20000;         // minimum sleeptime must be 20 sec, needed for the Heltec framework
  
  printf("sleep for %d ms\n", sleeptime);
  lora.sleep( sleeptime);
}

// setup
// initialize devices
void setup() {
  Serial.begin(115200); delay(500);
  Serial.println( "*** Starting Hittestress 2021 V" + String(VERSION) + " ***");

 printf( "resetRequest=%d\n", resetRequest);
  pinMode(Vext, OUTPUT);
  digitalWrite(Vext, HIGH);  // GPS off

 // assign soft Serial to SDS
  attachSDS();
  delay(1000); // wait for SDS is powered
  sds->sleep();  // v1.21
  
  while( !isPowerOk() ) {
    printf("Battery is too empty or not charging, sleep for %d ms\n", CYCLETIME);
    lora.sleep( CYCLETIME);
  }
  lora.setRxHandler( loraRxCallback); 
  lora.begin();

  Serial.println( "end setup");
}

// run loop
void loop() {
  worker();
  
  if( resetRequest) {   
    if( msgCount > 4) {    // prevent reset loop, caused by previous downlink reset command
      printf("HW RESET..\n"); delay(100);
      HW_Reset(0);
    }
    resetRequest = false;
  }

// periodical reset after 5000 cycles
  if( msgCount > 5000) {
     resetRequest = true;
  }
    
}


// LoRa receive handler (downnlink)
void loraRxCallback( int port, uint8_t* msg, int len) {
  printf("lora download message received port=%d cmd=%d len=%d\n", port, msg[0], len);
  // if port is 01 and command byte is 0xaa then reset the sensor
  if ( port == 1 && len == 1 && msg[0] == 0xaa) {
    resetRequest = true;
    printf("RESET COMMAND REVEIVED, planned in next cycle\n");
  }
}

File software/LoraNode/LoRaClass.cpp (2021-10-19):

/*--------------------------------------------------------------------
  LoRaClass wrapper class
  Hide he Heltec framework for the user and expose the convenient methods
  Author Marcel Meek
  Date 7/10/2021
  --------------------------------------------------------------------*/
#include "LoRaWanMinimal_APP.h"
#include "LoRaClass.h"

//Set these OTAA parameters to match your app/node in TTN
uint8_t devEui[8];  // Leave empty, the chip-id of the Heltec board is filled in after start-up
uint8_t appEui[] = { 0x70, 0xB3, 0xD5, 0x7E, 0xD0, 0x01, 0xFE, 0x1F };
uint8_t appKey[] = { 0x46, 0xBF, 0x7A, 0x1A, 0x2E, 0x95, 0x9F, 0xE9, 0xA6, 0xE8, 0xAE, 0x12, 0x12, 0xE5, 0x22, 0x35};

/*LoraWan channelsmask, default channels 0-7*/
uint16_t userChannelsMask[6] = { 0x00FF, 0x0000, 0x0000, 0x0000, 0x0000, 0x0000 };

static void (*_rxCallback)(int, uint8_t*, int) = NULL;

///////////////////////////////////////////////////
//Some utilities for going into low power mode
//TimerEvent_t sleepTimer;
//Records whether our sleep/low power timer expired
static bool sleepTimerExpired;
static TimerEvent_t sleepTimer;

static void wakeUp() {
  sleepTimerExpired=true;
}

static void lowPowerSleep(uint32_t sleeptime) {
  delay(10);  // some time to flush serial data
  sleepTimerExpired=false;
  TimerInit( &sleepTimer, &wakeUp );
  TimerSetValue( &sleepTimer, sleeptime );
  TimerStart( &sleepTimer );
  //Low power handler also gets interrupted by other timers
  //So wait until our timer had expired
  while (!sleepTimerExpired)
    lowPowerHandler();
  TimerStop( &sleepTimer );
}


//downlink data handle function
void downLinkDataHandle(McpsIndication_t *mcpsIndication)
{
  Serial.printf("Download message slot: %s\n", mcpsIndication->RxSlot?"RXWIN2":"RXWIN1");
  if( _rxCallback) {
    _rxCallback( mcpsIndication->Port, mcpsIndication->Buffer , mcpsIndication->BufferSize);
  }
}

LoRaClass::LoRaClass() {
  _rxCallback = NULL;
}

LoRaClass::~LoRaClass() {}

void LoRaClass::begin() {
  // get chip id and copy it to DEVEUI
  uint64_t chipID = getID();
  printf("DEVEUI: ");
  uint8_t *ptr = (uint8_t *)&chipID;
  for( int i=0; i<8; i++) {    // reverse copy
    devEui[i] = ptr[ 7-i];
    printf( "%02X ", devEui[i]);
  }
  printf("\n");
  
  LoRaWAN.begin(LORAWAN_CLASS, ACTIVE_REGION);  /*LoraWan region, select in arduino IDE tools*/
  //Enable ADR
  LoRaWAN.setAdaptiveDR(true);

  while( true) {
    Serial.print("Joining... ");
    LoRaWAN.joinOTAA(appEui, appKey, devEui);
    if (!LoRaWAN.isJoined()) {
      //In this example we just loop until we're joined, but you could
      //also go and start doing other things and try again later
      Serial.println("JOIN FAILED! Sleeping for 60 seconds");
      lowPowerSleep(60000);
    } else {
      Serial.println("JOINED");
      break;
    }
  }
}

void LoRaClass::sleep( int sleepTime) {
  lowPowerSleep( sleepTime);
}

void LoRaClass::setRxHandler( void (*callback)(int, uint8_t*, int)) {
  _rxCallback = callback;
}

void LoRaClass::send(int port, void *buf, int len) {
  if (LoRaWAN.send( len, (uint8_t *)buf, port, false))   // send unconfirmed
    Serial.println("Send OK");
  else
   Serial.println("Send FAILED");
}

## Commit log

2021-01-13 Update; PCB schema versie:001
2021-01-13 PCB design step
    [CubeCell_CAD2014.dwg, HittStress-21_20210112_BOMPlanning.xlsx, hitteStress21-pcb.kicad_pcb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]
2021-01-16 Updates on footprints
    [hitteStress21-pcb.kicad_pcb, hitteStress21-pcb.sch]
2021-01-17 PCB design updates
    [HittStress-21_20210112_BOMPlanning.xlsx, hitteStress21-pcb.kicad_pcb, hitteStress21-pcb.sch]
2021-02-16 Modified HTCC-AB01 footprint and updated PCB accordingly
    [hitteStress21-pcb.kicad_pcb]
2021-02-18 UPdate PCD, added support holes for antenna supports
    [hitteStress21-pcb.kicad_pcb]
2021-03-19 Added optional housing
2021-04-06 Start redesign PCB
    [HittStress-21_20210112_BOMPlanning.xlsx, hitteStress21-pcb.kicad_pcb]
2021-04-07 Update PCB
    [hitteStress21-pcb.kicad_pcb]
2021-04-08 Added frame for SDS011
    [SDS011Mount_004.dxf, SDS011Mount_004.skp]
2021-04-14 Added drill plan
    [HousingDrillMeasures_001.skp]
2021-04-16 Added drill drawing
    [SDS011Mount_001.skp, SDS011Mount_002.skp, SDS011Mount_003.skp]
2021-04-28 Added schema
    [hitteStress21-pcb.sch]
2021-04-28 Merged branch
    [SDS011Mount-3D_004.skp, SDS011Mount-3D_004.stl]
2021-06-18 update to V1.2
    - LiPO protection added, operation starts if Lipo is > 3.8v and goes in deepsleep if Lipo < 3.7v
    - wake-up SDS ipmproved
    - Switching between 2 soft serials ports improved
2021-10-19 Major update to V1.5
    New Heltec Framework V1.3 used
    Hang situation solved
    Battery management improved
    [LoRaClass.cpp, LoraNode.ino]
2021-10-19 HW diagram adapted
    AM2305 changed from 3.3Vtot 5V
    Elco's added, to absorb the switch-on current of the fan of the SDS011
